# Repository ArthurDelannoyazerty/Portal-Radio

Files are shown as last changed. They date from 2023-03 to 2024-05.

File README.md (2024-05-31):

# An arduino alarm clock/music player/clock !
This project is a fully functionnal alarm clock and music player. With this device, you can play music when you want and also wake up with them. The music are store on a mini SD card and played randomly, so no worrying about hearing the same music or ring each morning !!

No need to worry about the time if the device is disconected, a small battery inside the clock (RTC) keep the time ticking. You just need to replug the device and everything is working !

# Project Architecture

```
.
├── 📄 Wiring.fzz
|    └──> A Fritzing schematic of the project
├── 📁 3d
|    └──> Some 3D model that I have not printed yet
└── 📁 code
     ├── 📁 main
     |    └──> Contains the main script
     └── 📁 tests
          └──> Contains tests script for each individual element of the project (RTC, TFT, music player)
               A good way to debug your circuit if something is not working
```

# Components
- 1 Arduino UNO
- 1 TFT Screen (1.8) 
- 1 RTC module (DS3231)
- 1 Rotary encoder (KY040)
- 1 Music module (DFPlayer Mini)
- 1 USB module
- 1 Speaker (8 Ohms, 3W)
- 3 1K Omhs Resistor
- Optional (If noise in speaker when no music is played) :
    - 1 Relay (SRD-05VDC-SL-C)
    - 1 Transistor (2N2222)
    - 1 Diode
    - 2 Switch (TFT and Speaker)

# Libraries
- RTClib
- Wire
- TFT
- SPI
- SoftwareSerial
- DFRobotDFPlayerMini

# Project Utilisation
There is 3 main screens. Press the simple button to switch between these !
- ## Main Screen : Hour Display
    - Display the hour
    - The double dots slightly blink each second
    - Press the Rotary encoder button to activate/deactivate the alarm
- ## Alarm Screen
    - Display the alarm hour
    - Press the rotary encoder button to configure the alarm : 
        - Rotate the rotary encoder to change the digit
        - Press the rotary encoder to switch to another digit
- ## Music Screen
    - Display the volume
    - Press the rotary encoder button to activate the music :
        - A random music will start
        - Change music by pressing the button
        - Stop the music by pressing the rotary encoder button

# Some useful facts
- The music is randomly choosen
- The alarm is active only if you are in the main screen ! (At 2h30, the alarm auto change to the main screen(hour_force_hour_screen & minute_force_hour_screen line 50))
- The 2 switch are there to manually turn off the speaker or the TFT screen (useful if you want to sleep in silence and without light)
- When uploading the main code to arduino, be sure to uncomment the line ~150 :
  ```arduino
  rtc.adjust(DateTime(F(__DATE__),F(__TIME__)));
  ```
  in order to initialize the RTC with the time of the code compilation. Then upload again the code but with the same line commented in order to not reset the time to the compilation time every time the arduino restart.

# Wiring
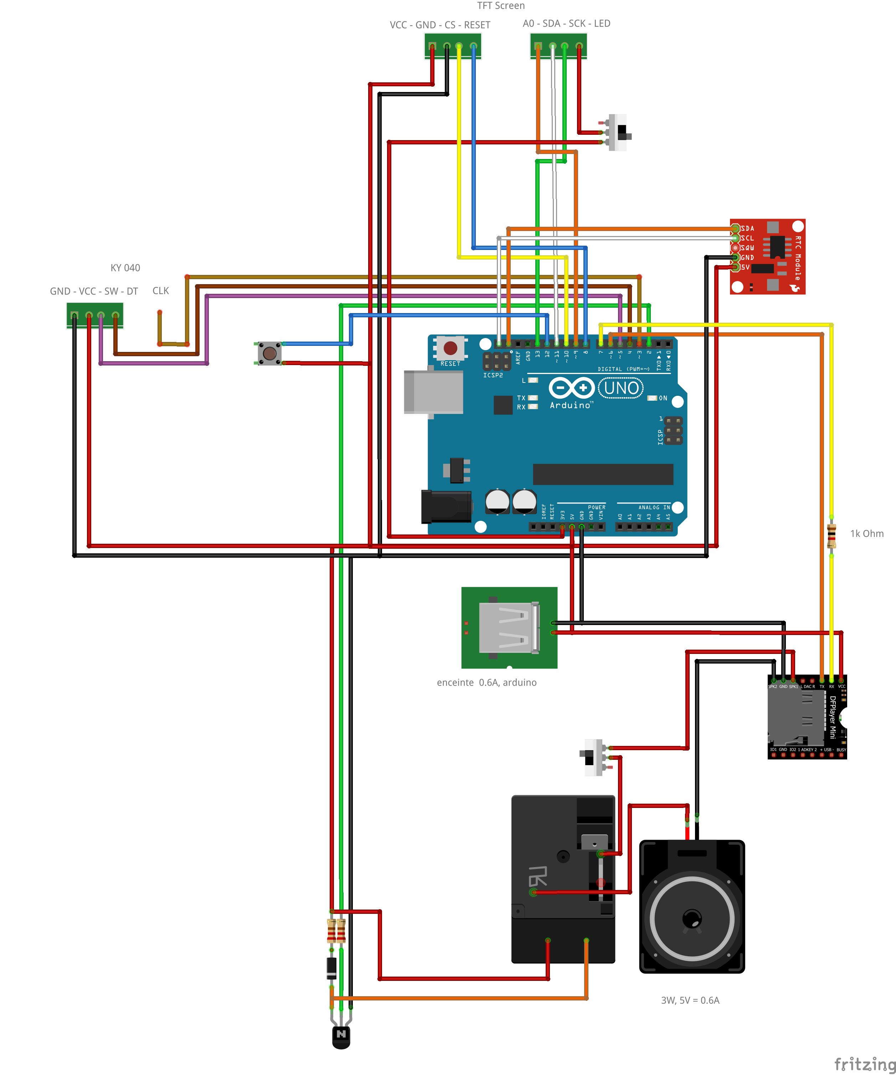
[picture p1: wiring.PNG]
Wiring


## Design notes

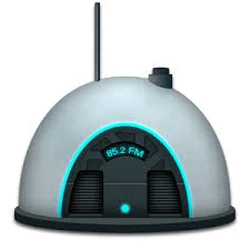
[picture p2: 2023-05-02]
3d/context_color_3Dprint.png

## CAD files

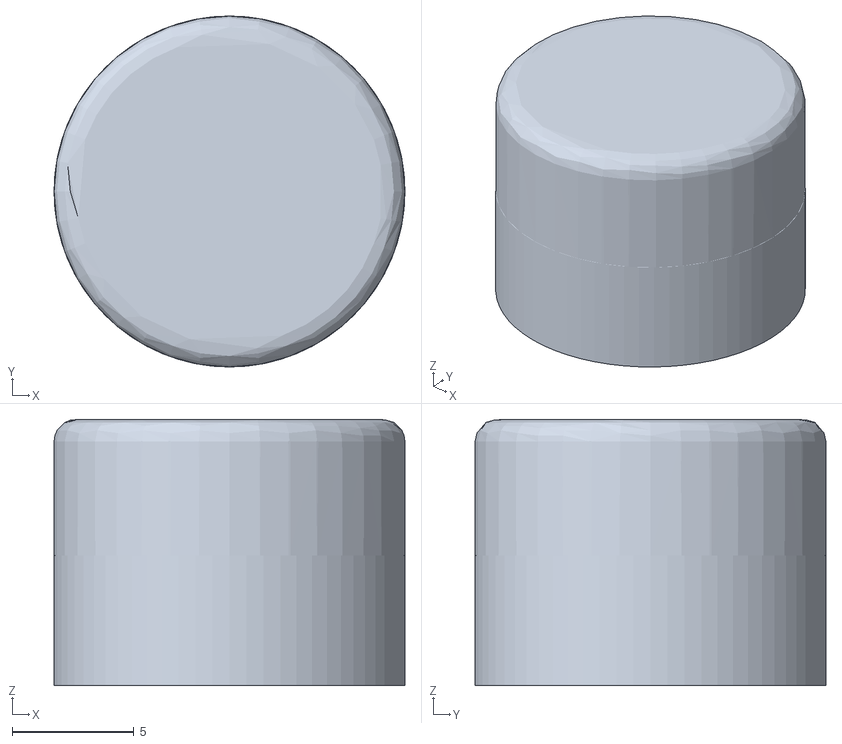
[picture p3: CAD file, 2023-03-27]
3d/base_elements/Portal_Radio_RPI_Zero_button_top.stl
14.4 x 14.4 x 10.9

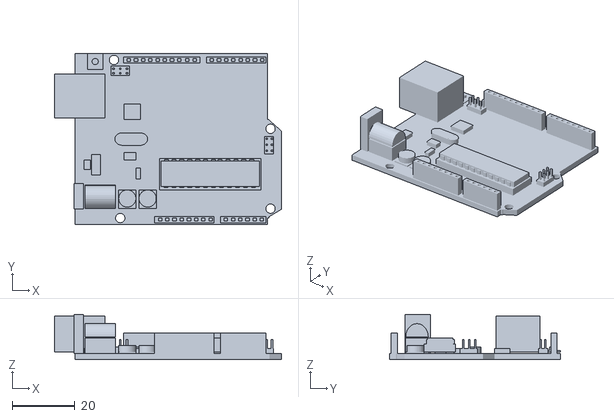
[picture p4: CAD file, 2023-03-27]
3d/base_elements/arduino 3d.stl
72.5 x 54.5 x 14.5

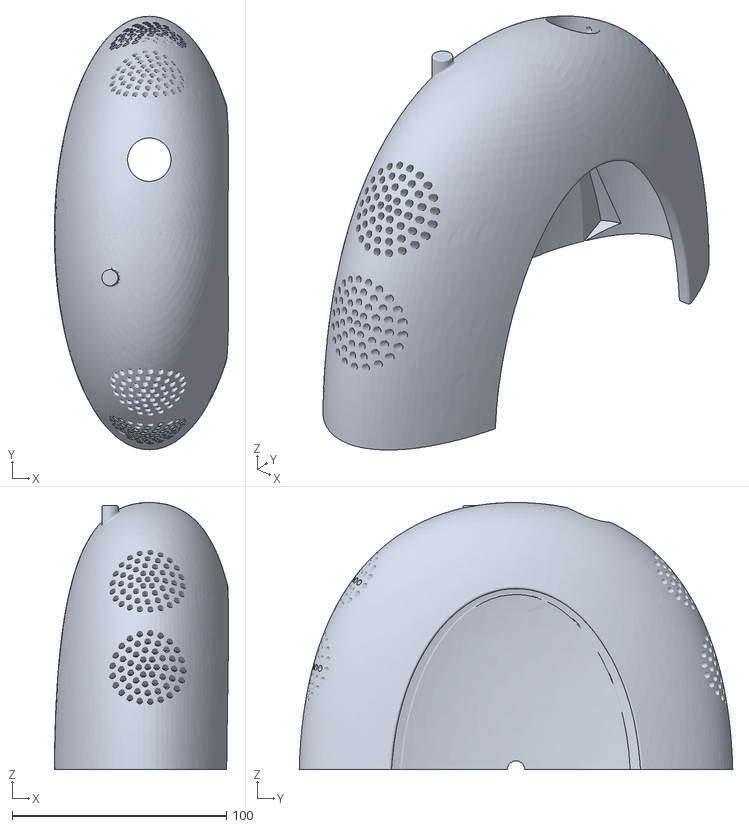
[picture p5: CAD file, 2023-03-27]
3d/base_elements/Portal_Radio_RPI_Zero_mod1_housing.stl
81.3 x 202.3 x 124.6

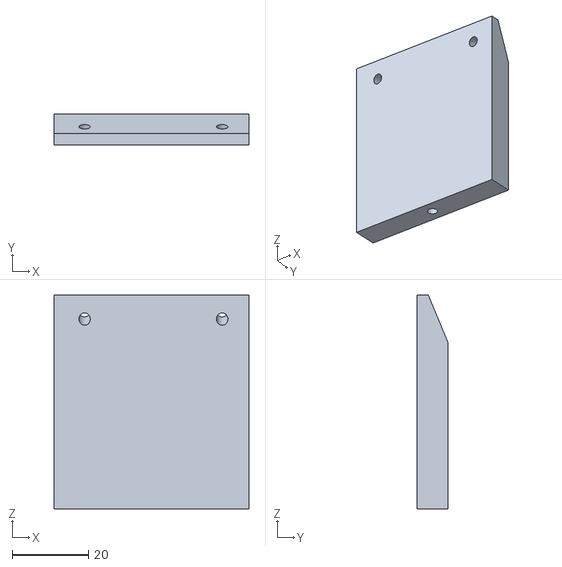
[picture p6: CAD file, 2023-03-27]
3d/base_elements/Portal_Radio_RPI_Zero_mod1_speaker_rig_solid.stl
51.0 x 8.00 x 56.0

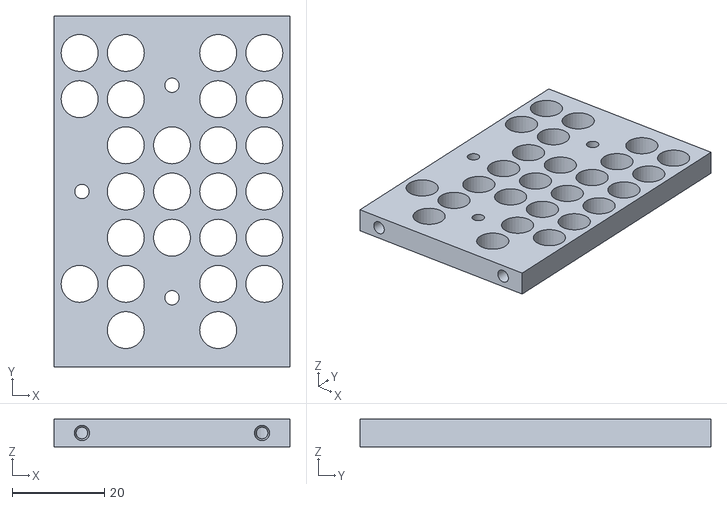
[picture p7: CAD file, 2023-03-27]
3d/base_elements/Portal_Radio_RPI_Zero_mod1_PSU_rig.stl
51.0 x 76.0 x 6.00

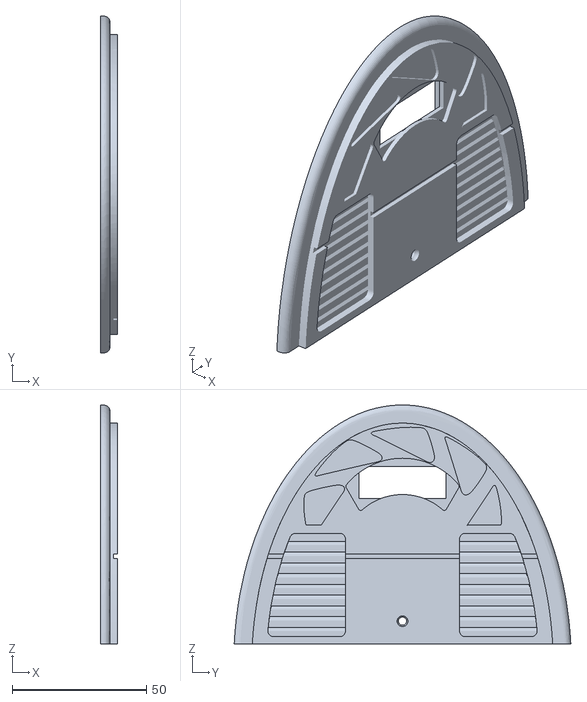
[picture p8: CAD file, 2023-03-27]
3d/base_elements/Portal_Radio_RPI_Zero_mod1_front.stl
6.20 x 125.2 x 88.9

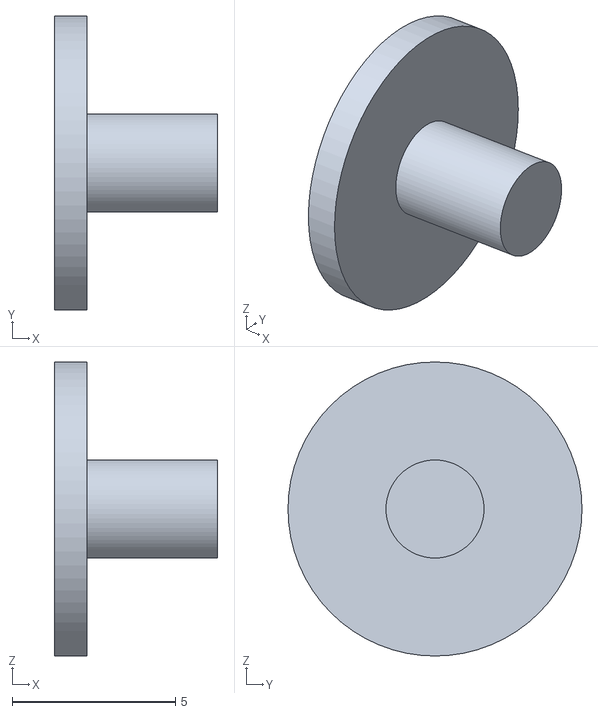
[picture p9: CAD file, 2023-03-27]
3d/base_elements/Portal_Radio_RPI_Zero_mod1_front_LED.stl
5.00 x 9.00 x 9.00

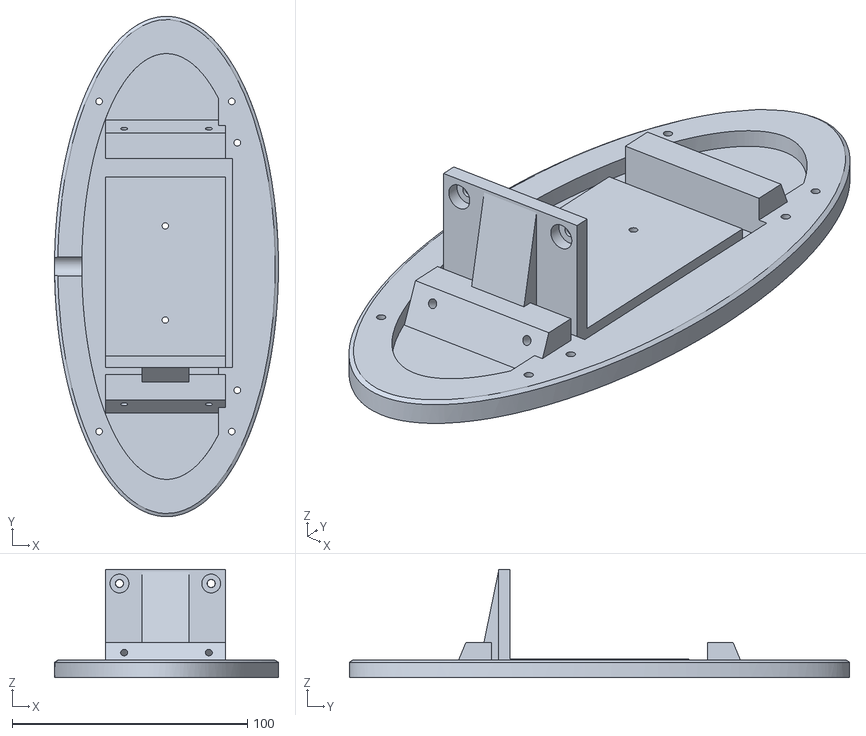
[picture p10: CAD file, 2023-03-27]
3d/base_elements/Portal_Radio_RPI_Zero_mod1_base.stl
95.2 x 212.7 x 46.0

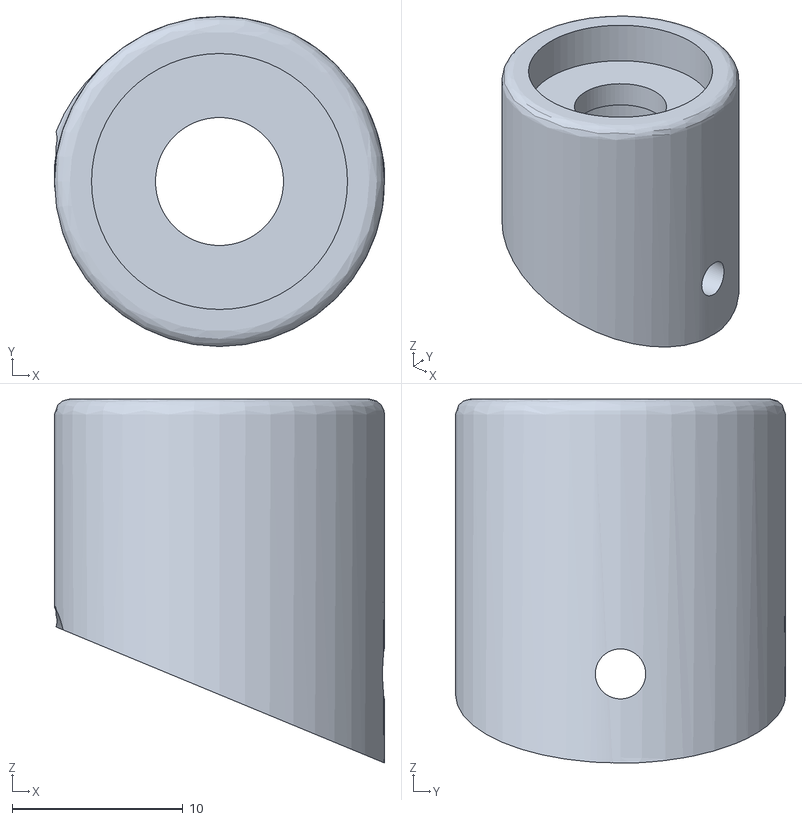
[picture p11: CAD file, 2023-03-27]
3d/base_elements/Portal_Radio_RPI_Zero_button_base.stl
19.4 x 19.4 x 21.3

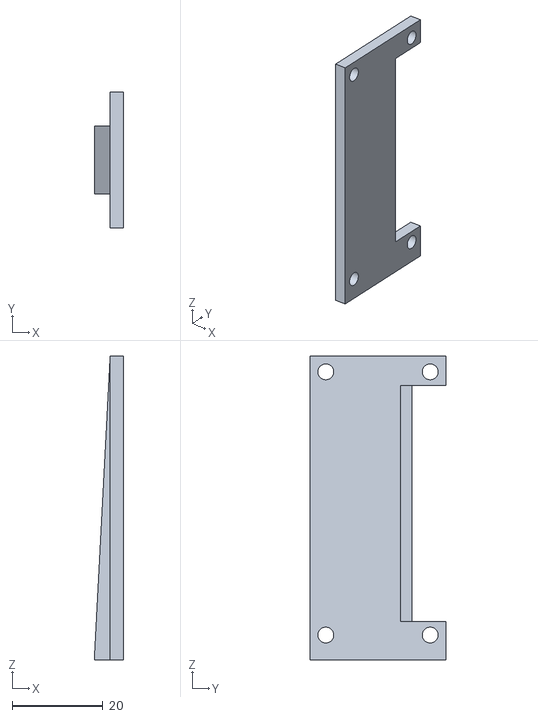
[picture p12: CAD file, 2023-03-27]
3d/base_elements/Portal_Radio_RPI_Zero_mod1_rpi_rig.stl
6.50 x 30.0 x 67.0

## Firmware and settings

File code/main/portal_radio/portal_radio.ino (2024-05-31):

// DS3231
#include <RTClib.h>
#include <Wire.h>
RTC_DS3231 rtc;
char t[32];

// TFT
#include <TFT.h>
#include <SPI.h>
#define cs 10
#define dc 9
#define rst 8
TFT TFTscreen = TFT(cs, dc, rst);

// MP3-TF-16P V3.0
#include "Arduino.h"
#include "DFRobotDFPlayerMini.h"
#include <SoftwareSerial.h>
SoftwareSerial softSerial(/*rx =*/6, /*tx =*/7);
#define FPSerial softSerial
DFRobotDFPlayerMini myDFPlayer;

// PROJECT
#define position_hour_tens 5, 50
#define position_hour_unit 35, 50
#define position_double_points 65, 50
#define position_minute_tens 95, 50
#define position_minute_unit 125, 50

#define relay_pin 2

#define sw_pin 5
#define dt_pin 4
#define clk_pin 3

#define button_pin 12

#define tft_background_color 0, 0, 0
#define tft_text_color 222, 222, 73
#define tft_text_color_darker 88, 88, 16

#define max_volume_music 25
#define min_volume_music 1

// ---------------------------------------
char charHour[2];
char charMinute[2];
char charSecond[2];

int hour_force_hour_screen = 2;
int minute_force_hour_screen = 30;

int previous_hour_tens   = -1;
int previous_hour_unit   = -1;
int previous_minute_tens = -1;
int previous_minute_unit = -1;
int previous_seconds     = -1;
bool double_dots_darker = true;

int alarm_hour = 7;
int alarm_minute = 30;
bool alarm_active = false;
bool alarm_logo_visible = false;
bool alarm_temporary_disabled = false;
bool alarm_alarming = false;

int volume_music = 11;

int compteur_rotary = 0;
int etatPrecedentLigneSW;
int etatPrecedentLigneCLK;

bool previous_simple_button_state = false;
bool previous_rotary_button_state = false;

bool simple_button_rising = false;
bool rotary_button_rising = false;

bool temp_disable_alarm_override = false;

int clock_logo[52][2] = {
    { 0, 4 },
    { 0, 5 },
    { 0, 6 },
    { 0, 7 },
    { 1, 2 },
    { 1, 3 },
    { 1, 4 },
    { 1, 7 },
    { 1, 8 },
    { 1, 9 },
    { 2, 1 },
    { 2, 2 },
    { 2, 9 },
    { 2, 10 },
    { 3, 1 },
    { 3, 5 },
    { 3, 10 },
    { 4, 0 },
    { 4, 1 },
    { 4, 5 },
    { 4, 10 },
    { 4, 11 },
    { 5, 0 },
    { 5, 5 },
    { 5, 11 },
    { 6, 0 },
    { 6, 5 },
    { 6, 6 },
    { 6, 7 },
    { 6, 8 },
    { 6, 11 },
    { 7, 0 },
    { 7, 1 },
    { 7, 10 },
    { 7, 11 },
    { 8, 1 },
    { 8, 10 },
    { 9, 1 },
    { 9, 2 },
    { 9, 9 },
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
  };

enum { HOUR_SCREEN,
       INIT_ALARM_SCREEN,
       ALARM_SCREEN,
       INIT_MUSIC_SCREEN,
       MUSIC_SCREEN };
int main_state = HOUR_SCREEN;


bool configuring_alarm = false;

void setup() {
  Serial.begin(9600);
  // DS3231
  Wire.begin();
  rtc.begin();
  // rtc.adjust(DateTime(F(__DATE__),F(__TIME__)));     // Uncomment to set current time

  // TFT screen
  TFTscreen.begin();
  TFTscreen.background(tft_background_color);
  TFTscreen.setTextSize(5);

  // MP3 player
  FPSerial.begin(9600);
  if (!myDFPlayer.begin(FPSerial, /*isACK = */ true, /*doReset = */ true)) {  //Use serial to communicate with mp3.
    Serial.println(F("Unable to begin: Please recheck the connection or insert the SD card!"));
    while (true) {
      delay(0);  // Code to compatible with ESP8266 watch dog.
    }
  }
  myDFPlayer.volume(volume_music);

  //////////////////////////// MUSIC ////////////////////////////////////////
  pinMode(relay_pin, OUTPUT);  // Relay activation
  power_to_speaker(false);

  //////////////////////////// POTENTIOMETRE//////////////////////////////////
  pinMode(sw_pin, INPUT_PULLUP);
  pinMode(dt_pin, INPUT);
  pinMode(clk_pin, INPUT);

  etatPrecedentLigneSW = digitalRead(sw_pin);
  etatPrecedentLigneCLK = digitalRead(clk_pin);

  //////////////////////////////////////////////////////////////////////////
  pinMode(button_pin, INPUT);
}

void loop() {
  scan_buttons();
  force_hour_screen();
  if (!temp_disable_alarm_override) check_alarm();
  switch (main_state) {
    case HOUR_SCREEN:
      if (rotary_button_rising) alarm_active = !alarm_active;
      if (alarm_active  && !alarm_logo_visible) display_clock_logo(true);
      if (!alarm_active &&  alarm_logo_visible) display_clock_logo(false);
      display_current_time_tft();
      if (simple_button_rising){
        if (alarm_alarming) myDFPlayer.next();
        else{
          reset_tft();
          main_state=INIT_ALARM_SCREEN;
        }
      }
      if (alarm_alarming){
        int rotation_volume = get_button_rotation();
        if (rotation_volume!=0){
          volume_music += rotation_volume;
          if (volume_music>max_volume_music) volume_music=max_volume_music;
          if (volume_music<min_volume_music) volume_music=min_volume_music;
          myDFPlayer.volume(volume_music);
        }
      }
      break;
    case INIT_ALARM_SCREEN:
      TFTscreen.setTextSize(2);
      TFTscreen.setCursor(50,20);
      TFTscreen.stroke(tft_text_color);
      TFTscreen.println("ALARM");
      display_alarm_time(-1, false);
      main_state = ALARM_SCREEN;
      break;
    case ALARM_SCREEN:
      if (rotary_button_rising) configuring_alarm = true;
      if (configuring_alarm){
        int index_number_blink = 0;
        while (true){
          delay(1);
          scan_buttons();
          display_alarm_time(index_number_blink, false);
          int rotation = get_button_rotation();
          if (index_number_blink==0){
            alarm_hour += rotation*10;
            if      (alarm_hour<0      && rotation==-1) alarm_hour += 30;
            else if (alarm_hour/10==3  && rotation==1)  alarm_hour -= 30;
          }
          if (index_number_blink==1){
            if (alarm_hour>23) alarm_hour = 23;
            alarm_hour += rotation;
            if      (alarm_hour<0    && rotation==-1) alarm_hour += 24;
            else if (alarm_hour==24  && rotation==1)  alarm_hour -= 24;
          }
          if (index_number_blink==2){
            alarm_minute += rotation*10;
            if      (alarm_minute<0     && rotation==-1) alarm_minute += 60;
            else if (alarm_minute/10==6 && rotation==1)  alarm_minute -= 60;
          }
          if (index_number_blink==3){
            if (alarm_minute>59) alarm_minute = 59;
            alarm_minute += rotation;
            if      (alarm_minute<0    && rotation==-1) alarm_minute += 60;
            else if (alarm_minute==60  && rotation==1)  alarm_minute -= 60;
          }
          if (rotary_button_rising){
            index_number_blink++;
            display_alarm_time(-1, true);
          }
          if (index_number_blink==4){ 
            configuring_alarm = false;
            break;
          }
        }
      }
      if (simple_button_rising){
        reset_tft();
        main_state = INIT_MUSIC_SCREEN; 
      }
      break;
    case INIT_MUSIC_SCREEN:
      TFTscreen.setTextSize(2);
      TFTscreen.stroke(tft_text_color);
      TFTscreen.setCursor(50,20);
      TFTscreen.println("MUSIC");
      TFTscreen.setCursor(25,55);
      TFTscreen.println("VOLUME");
      TFTscreen.setCursor(105,55);
      TFTscreen.println(volume_music);
      temp_disable_alarm_override = true;
      main_state = MUSIC_SCREEN;
      break;
    case MUSIC_SCREEN:
      if (rotary_button_rising){
        if (alarm_alarming){
          power_to_speaker(false);
          myDFPlayer.pause();
          alarm_alarming = false;
        }
        else if (!alarm_alarming){
          power_to_speaker(true);
          myDFPlayer.randomAll();
          alarm_alarming = true;
        }
      }
      int rotation_music = get_button_rotation();
      if (rotation_music==1){
        volume_music += 1;
        if (volume_music>max_volume_music) volume_music=max_volume_music;
        myDFPlayer.volume(volume_music);
        TFTscreen.setTextSize(2);
        TFTscreen.stroke(tft_background_color);
        TFTscreen.setCursor(105,55);
        TFTscreen.println(volume_music-1);
        TFTscreen.stroke(tft_text_color);
        TFTscreen.setCursor(105,55);
        TFTscreen.println(volume_music);
      }
      else if (rotation_music==-1){
        volume_music -= 1;
        if (volume_music<min_volume_music) volume_music=min_volume_music;
        myDFPlayer.volume(volume_music);
        TFTscreen.setTextSize(2);
        TFTscreen.stroke(tft_background_color);
        TFTscreen.setCursor(105,55);
        TFTscreen.println(volume_music+1);
        TFTscreen.stroke(tft_text_color);
        TFTscreen.setCursor(105,55);
        TFTscreen.println(volume_music);
      }
      if (simple_button_rising){
        if (!alarm_alarming){
          reset_tft();
          main_state = HOUR_SCREEN;
          temp_disable_alarm_override = false;
        }
        else{
          myDFPlayer.next();
        }
      }
      break;
  }
}


void force_hour_screen(){
  DateTime now = rtc.now();
  int hour = now.hour();
  int minute = now.minute();
  int seconds = now.second();

  if (main_state!=HOUR_SCREEN && hour==hour_force_hour_screen && minute==minute_force_hour_screen && seconds==58 && !alarm_alarming){
    reset_tft();
    main_state = HOUR_SCREEN;
  }
}

void reset_tft(){
  TFTscreen.background(tft_background_color);
  previous_hour_tens   = -1;
  previous_hour_unit   = -1;
  previous_minute_tens = -1;
  previous_minute_unit = -1;
  previous_seconds     = -1;
  alarm_logo_visible = false;
}


void check_alarm(){
  if (alarm_active){
    DateTime now = rtc.now();
    int hour = now.hour();
    int minute = now.minute();
    int seconds = now.second();

    if (alarm_hour==hour && alarm_minute==minute && seconds==58){
      power_to_speaker(true);
      myDFPlayer.randomAll();
      alarm_alarming = true;
    }
  }
  if (alarm_alarming && rotary_button_rising){
    power_to_speaker(false);
    myDFPlayer.pause();
    alarm_alarming = false;
    alarm_active = false;
  }
}


void scan_buttons(){
  bool simple_button_pressed = is_simple_button_pressed();
  bool rotary_button_pressed = is_rotary_button_pressed();

  simple_button_rising = simple_button_pressed && !previous_simple_button_state;
  rotary_button_rising = rotary_button_pressed && !previous_rotary_button_state;

  previous_simple_button_state = simple_button_pressed;
  previous_rotary_button_state = rotary_button_pressed;
}




void display_clock_logo(bool enable){
  alarm_logo_visible = enable;
  enable ? TFTscreen.stroke(tft_text_color) : TFTscreen.stroke(tft_background_color);
  for (int i = 0; i < 51; i++) {
    TFTscreen.point(10 + clock_logo[i][1], 10 + clock_logo[i][0]);
  }
}


bool is_rotary_button_pressed() {
  int etatActuelDeLaLigneSW = digitalRead(sw_pin);
  bool button_pressed = false;

  if (etatActuelDeLaLigneSW != etatPrecedentLigneSW) {
    if (etatActuelDeLaLigneSW == LOW) button_pressed = true;
    delay(10);
  }
  return button_pressed;
}

bool is_simple_button_pressed(){
  return digitalRead(button_pin);
}

int get_button_rotation() {
  int etatActuelDeLaLigneCLK = digitalRead(clk_pin);
  int etatActuelDeLaLigneDT = digitalRead(dt_pin);
  int rotation = 0;
  if (etatActuelDeLaLigneCLK != etatPrecedentLigneCLK) {
    etatPrecedentLigneCLK = etatActuelDeLaLigneCLK;
    if (etatActuelDeLaLigneCLK == LOW) {
      etatActuelDeLaLigneCLK != etatActuelDeLaLigneDT ? rotation = -1 : rotation = 1;
      delay(1);
    }
  }
  return rotation;
}


void power_to_speaker(bool power) {
  power ? digitalWrite(relay_pin, HIGH) : digitalWrite(relay_pin, LOW);
}


void display_alarm_time(int index_blink, bool force_display){
  DateTime now = rtc.now();
  int second = now.second();

  display_time_tft(alarm_hour/10, alarm_hour%10, alarm_minute/10, alarm_minute%10, second, index_blink, force_display);
}


void display_current_time_tft() {
  DateTime now = rtc.now();
  int hour = now.hour();
  int minute = now.minute();
  int second = now.second();

  display_time_tft(hour/10, hour%10, minute/10, minute%10, second, -1, false);
}


void display_time_tft(int hour_tens, int hour_unit, int minute_tens, int minute_unit, int second, int index_number_blink, bool force_display){
  TFTscreen.setTextSize(5);
  if (hour_tens != previous_hour_tens || force_display) {    //TODO alarm also
    TFTscreen.stroke(tft_background_color);
    TFTscreen.setCursor(position_hour_tens);
    TFTscreen.println(previous_hour_tens);
    TFTscreen.stroke(tft_text_color);
    TFTscreen.setCursor(position_hour_tens);
    TFTscreen.println(hour_tens);
    previous_hour_tens = hour_tens;
  }
  if (hour_unit != previous_hour_unit || force_display) {
    TFTscreen.stroke(tft_background_color);
    TFTscreen.setCursor(position_hour_unit);
    TFTscreen.println(previous_hour_unit);
    TFTscreen.stroke(tft_text_color);
    TFTscreen.setCursor(position_hour_unit);
    TFTscreen.println(hour_unit);
    previous_hour_unit = hour_unit;
  }

  if (minute_tens != previous_minute_tens || force_display) {
    TFTscreen.stroke(tft_background_color);
    TFTscreen.setCursor(position_minute_tens);
    TFTscreen.println(previous_minute_tens);
    TFTscreen.stroke(tft_text_color);
    TFTscreen.setCursor(position_minute_tens);
    TFTscreen.println(minute_tens);
    previous_minute_tens = minute_tens;
  }
  if (minute_unit != previous_minute_unit || force_display) {
    TFTscreen.stroke(tft_background_color);
    TFTscreen.setCursor(position_minute_unit);
    TFTscreen.println(previous_minute_unit);
    TFTscreen.stroke(tft_text_color);
    TFTscreen.setCursor(position_minute_unit);
    TFTscreen.println(minute_unit);
    previous_minute_unit = minute_unit;
  }

  if (second != previous_seconds) {
    second % 2 == 0 ? TFTscreen.stroke(tft_text_color) : TFTscreen.stroke(tft_text_color_darker);
    TFTscreen.setCursor(position_double_points);
    TFTscreen.println(":");
    previous_seconds = second;

    if (configuring_alarm){
      if (index_number_blink==0){
        TFTscreen.setCursor(position_hour_tens);
        TFTscreen.println(hour_tens);
      }
      if (index_number_blink==1){
        TFTscreen.setCursor(position_hour_unit);
        TFTscreen.println(hour_unit);
      }
      if (index_number_blink==2){
        TFTscreen.setCursor(position_minute_tens);
        TFTscreen.println(minute_tens);
      }
      if (index_number_blink==3){
        TFTscreen.setCursor(position_minute_unit);
        TFTscreen.println(minute_unit);
      }
    }
  }
}

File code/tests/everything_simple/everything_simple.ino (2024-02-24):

// DS3231
#include <RTClib.h>
#include <Wire.h>
RTC_DS3231 rtc;
char t[32];

// TFT
#include <TFT.h>  
#include <SPI.h>
#define cs   10
#define dc   9
#define rst  8
TFT TFTscreen = TFT(cs, dc, rst);

// MP3-TF-16P V3.0
#include "Arduino.h"
#include "DFRobotDFPlayerMini.h"
#include <SoftwareSerial.h>
SoftwareSerial softSerial(/*rx =*/6, /*tx =*/7);
#define FPSerial softSerial
DFRobotDFPlayerMini myDFPlayer;

// PROJECT
#define position_hour 5,5
#define position_minute 5,55
#define position_second 5,105

#define relay_pin 2

#define sw_pin  5
#define dt_pin  4
#define clk_pin 3

// ---------------------------------------
char charHour[2]; 
char charMinute[2]; 
char charSecond[2]; 

int previous_hour;
int previous_minute;
int previous_second;

int compteur_rotary = 0;
int etatPrecedentLigneSW;
int etatPrecedentLigneCLK;


void setup() {
  Serial.begin(9600);

  // DS3231
  Wire.begin();
  rtc.begin();
  // rtc.adjust(DateTime(F(__DATE__),F(__TIME__)));     // Uncomment to set current time


  // TFT screen
  TFTscreen.begin();
  TFTscreen.background(0, 0, 0);
  TFTscreen.setTextSize(2);

  // MP3 player
  FPSerial.begin(9600);
  if (!myDFPlayer.begin(FPSerial, /*isACK = */true, /*doReset = */true)) {  //Use serial to communicate with mp3.
    Serial.println(F("Unable to begin: Please recheck the connection or insert the SD card!"));
    while(true){
      delay(0); // Code to compatible with ESP8266 watch dog.
    }
  }

  
  //////////////////////////// INIT TIME ON SCREEN ////////////////////////////////////////
  DateTime now = rtc.now();
  int hour = now.hour();
  int minute = now.minute();
  int second = now.second();

  TFTscreen.stroke(255, 255, 255);
  TFTscreen.setCursor(5, 5);
  TFTscreen.println(hour);
  TFTscreen.setCursor(5, 55);
  TFTscreen.println(minute);
  TFTscreen.setCursor(5, 105);
  TFTscreen.println(second);

  previous_hour = hour;
  previous_minute = minute;
  previous_second = second;


  //////////////////////////// MUSIC ////////////////////////////////////////
  
  pinMode(relay_pin, OUTPUT);    // Relay activation
  power_to_speaker(true);

  //////////////////////////// POTENTIOMETRE//////////////////////////////////
    pinMode(sw_pin, INPUT_PULLUP);
    pinMode(dt_pin, INPUT);
    pinMode(clk_pin, INPUT);

    etatPrecedentLigneSW  = digitalRead(sw_pin);
    etatPrecedentLigneCLK = digitalRead(clk_pin);

    Serial.println(myDFPlayer.readFolderCounts());
    Serial.println(myDFPlayer.readFileCounts());
    
    myDFPlayer.volume(10);  //Set volume value. From 0 to 30
    myDFPlayer.play();
    power_to_speaker(true);
}

void loop() {
  // delay(1000);
  display_time_tft();
  refresh_compteur_rotary();
}

void refresh_compteur_rotary(){
    int etatActuelDeLaLigneCLK = digitalRead(clk_pin);
    int etatActuelDeLaLigneSW  = digitalRead(sw_pin);
    int etatActuelDeLaLigneDT  = digitalRead(dt_pin);

    if(etatActuelDeLaLigneSW != etatPrecedentLigneSW) {
        if(etatActuelDeLaLigneSW == LOW)  Serial.println(F("Bouton SW appuyé"));
        else                              Serial.println(F("Bouton SW relâché"));
        delay(10);
    }
    if(etatActuelDeLaLigneCLK != etatPrecedentLigneCLK) {
      etatPrecedentLigneCLK = etatActuelDeLaLigneCLK;
      if(etatActuelDeLaLigneCLK == LOW) {
        if(etatActuelDeLaLigneCLK != etatActuelDeLaLigneDT) {
            compteur_rotary--;
            Serial.println(compteur_rotary);
        }
        else {
            compteur_rotary++;
            Serial.println(compteur_rotary);
        }
        delay(1);
      }
    }
}

void power_to_speaker(bool power){
  power ? digitalWrite(relay_pin, HIGH) : digitalWrite(relay_pin, LOW);
}


void display_time_tft(){
  DateTime now = rtc.now();
  int hour = now.hour();
  int minute = now.minute();
  int second = now.second();

  if (hour != previous_hour){
    TFTscreen.stroke(0, 0, 0);
    TFTscreen.setCursor(position_hour);
    TFTscreen.println(previous_hour);
    TFTscreen.stroke(255, 255, 255);
    TFTscreen.setCursor(position_hour);
    TFTscreen.println(hour);
    previous_hour = hour;
  }

  if (minute != previous_minute){
    TFTscreen.stroke(0, 0, 0);
    TFTscreen.setCursor(position_minute);
    TFTscreen.println(previous_minute);
    TFTscreen.stroke(255, 255, 255);
    TFTscreen.setCursor(position_minute);
    TFTscreen.println(minute);
    previous_minute = minute;
  }

  if (second != previous_second){
    TFTscreen.stroke(0, 0, 0);
    TFTscreen.setCursor(position_second);
    TFTscreen.println(previous_second);
    TFTscreen.stroke(255, 255, 255);
    TFTscreen.setCursor(position_second);
    TFTscreen.println(second);
    previous_second = second;
  }
}

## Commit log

2023-03-27 3d files added
    [Portal_Radio_RPI_Zero_button_base.stl, Portal_Radio_RPI_Zero_button_top.stl, Portal_Radio_RPI_Zero_mod1_PSU_rig.stl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]
2023-03-28 wiring tft screen added
    [Wiring.fzz]
2023-04-04 added 3D final model
    [Portal_Radio_RPI_Zero_button_base.stl, Portal_Radio_RPI_Zero_button_top.stl, Portal_Radio_RPI_Zero_mod1_PSU_rig.stl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]
2023-04-04 several speakers added wiring
    [Wiring.fzz]
2023-04-15 added controller components wiring
    [Wiring.fzz]
2023-05-02 added code test and initialize + update wiring
    [Wiring.fzz]
2023-11-23 added wiring png
2023-12-09 fix mp3 + update wiring + test everything
    [Wiring.fzz]
2023-12-09 forget to save
    [Wiring.fzz]
2023-12-10 added print time on tft
    [Wiring.fzz]
2024-02-22 added test rotary encoder(+in simple test all) + comment wire.h for serial
2024-02-24 rewiring on big plate
2024-02-25 updated wiring
    [Wiring.fzz]
2024-03-19 final wiring
    [Wiring.fzz]
